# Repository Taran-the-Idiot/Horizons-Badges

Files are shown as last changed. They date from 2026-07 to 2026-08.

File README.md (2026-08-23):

# Horizons Crux Badges



E-ink badges for Horizons Crux! Made in Kicad. They use 2.66" E-ink screens with an RP2040 mcu. And they are made in the shape of a mantaray :D

Just use a piece of double sided tape to secure down the screen and you are good to go!

Features: 

- usbC connector
- 2.66" E-ink
- No battery required
- Has a lanyard hole

## Schematic



Here is the schematic for this board. It is a normal rp2040 microcontroller with an E-ink driver integrated into it. 

## PCB



Here is the pcb layout and design. This is a 2 layer board that has a ground pour, as well as a 3v3 pour on the top side over where the mcu electronics are. 

The files for the individual art sections can be found labelled in the [/art](/art) directory.

### Art

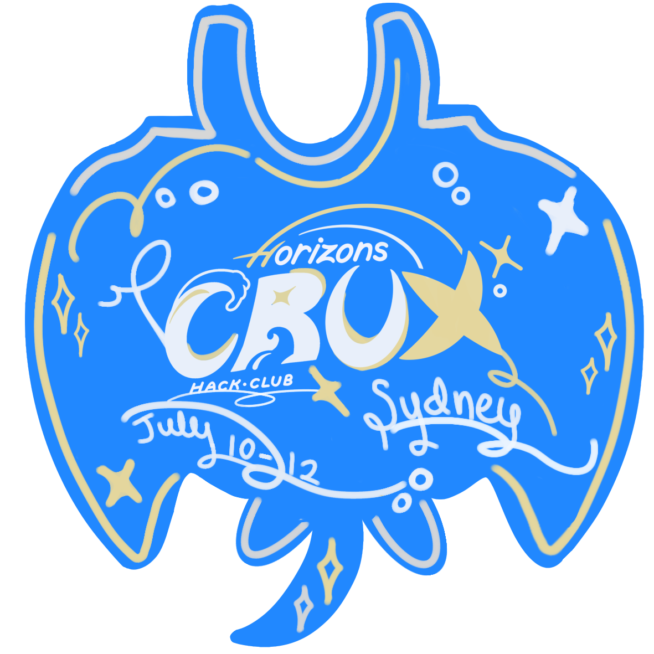
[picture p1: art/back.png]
fkdsjflkd


The art was drawn by [@variidian](https://github.com/variidian). The original art files and the vectorised sections for pcb production can be found in the [/art](/art) folder. 

## Firmware

The badge can be flashed using the [Badge Paint Website](https://badge-paint.notaroomba.dev/).

You draw what you want or load in the preset and fill in the details. you then need to flash a micropython .uf2 and it will then allow you to flash the badge.

This site was made by [@notaroomba](https://github.com/notaroomba)

#### Credits

Credit to [@variidian](https://github.com/variidian) for making the art for the badge and credit to [@notaroomba](https://github.com/notaroomba) for writing the software.

Also a thank you to [JLCPCB](https://jlcpcb.com) for sponsoring the badges!

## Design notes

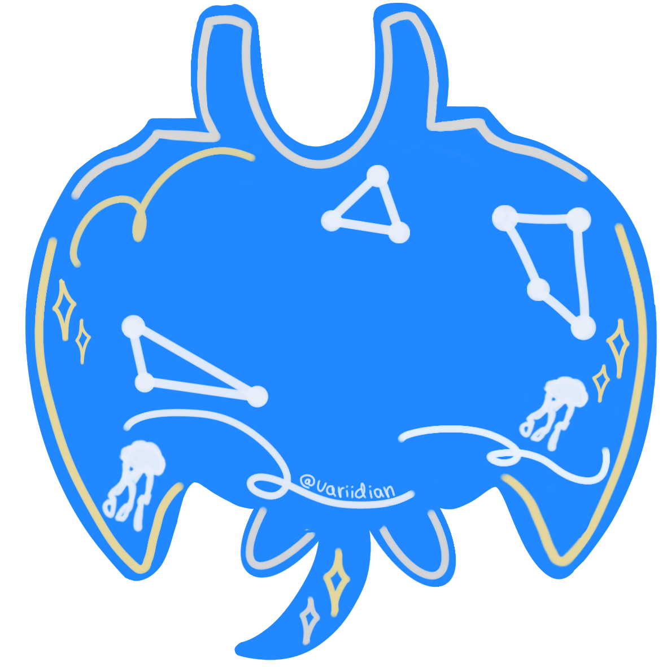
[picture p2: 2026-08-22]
art/front.png

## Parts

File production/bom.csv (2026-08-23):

Designator | Footprint | Quantity | Value | LCSC Part #
C1, C20, C22, C23, C24, C25, C26, C27, C28, C29, C9 | 0402 | 11 | 1uf
C10, C11, C12, C17, C2, C21, C3, C4, C5, C6, C7, C8 | 0402 | 12 | 100nf
C13, C14 | 0603 | 2 | 33pf
C15, C16 | 0603 | 2 | 10uf
C18, C19 | 0402 | 2 | 4.7uf
D1 | 0805 | 1 | C2293
D2, D3, D4 | SOD-123_L2.8-W1.8-LS3.7-RD | 3 | MBR0530
J1 | USB-C-SMD_20P-P0.50-L6.5-W8.9 | 1 | C309365
L1 | IND-SMD_L4.0-W4.0_FNR40XXS | 1 | 10uh 1A
Q1 | SOT-23 | 1 | C5122027
R1, R4, R5 | 0402 | 3 | 1k
R10 | 0402 | 1 | 0.47
R11 | 0603 | 1 | 10k
R2 | 0402 | 1 | 10k
R3 | 0402 | 1 | 2.2k
R6, R7 | 0402 | 2 | 22
R8, R9 | 0402 | 2 | 5.1k
SW1, SW2 | C720477 | 2 | C720477
U1 | QFN-56-1EP_7x7mm_P0.4mm_EP3.2x3.2mm_ThermalVias | 1 | C2040
U2 | SOIC-8_5.3x5.3mm_P1.27mm | 1 | W25Q16JVSS
U3 | FPC-SMD_24P-P0.50_05A20L24P | 1 | ~
U4 | SOT-23 | 1 | XC6206P332MR
U5 | SOT-23-6 | 1 | USBLC6-2SC6
Y1 | CRYSTAL-SMD_4P-L3.2-W2.5-BL | 1 | C9002

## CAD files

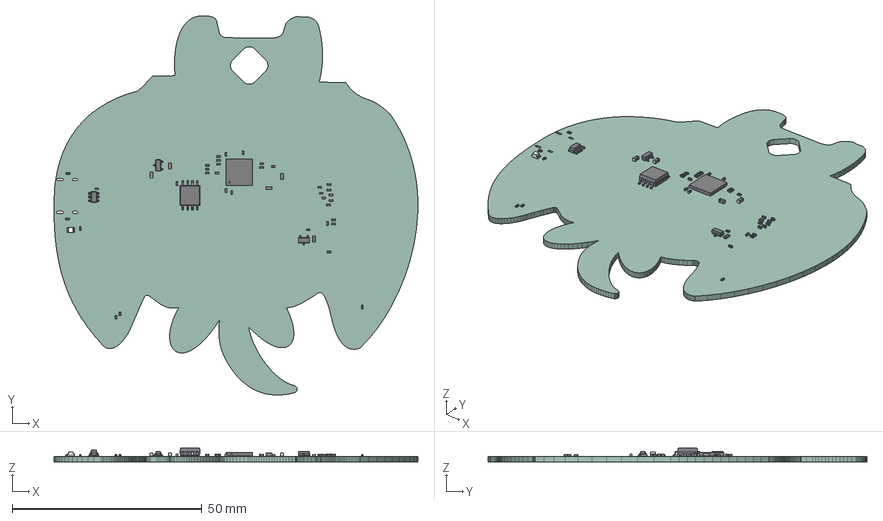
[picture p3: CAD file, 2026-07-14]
PCB/pcb.step
96.0 x 99.9 x 3.75 mm
LED_0805_2012Metric
C_0402_1005Metric x 25
R_0402_1005Metric x 10
C_0603_1608Metric x 4
SOT-23-6
SOT-23 x 2
R_0603_1608Metric
QFN-56-1EP_7x7mm_P0.4mm_EP3.2x3.2mm
SOIC-8_5.3x5.3mm_P1.27mm
PCB_PCB

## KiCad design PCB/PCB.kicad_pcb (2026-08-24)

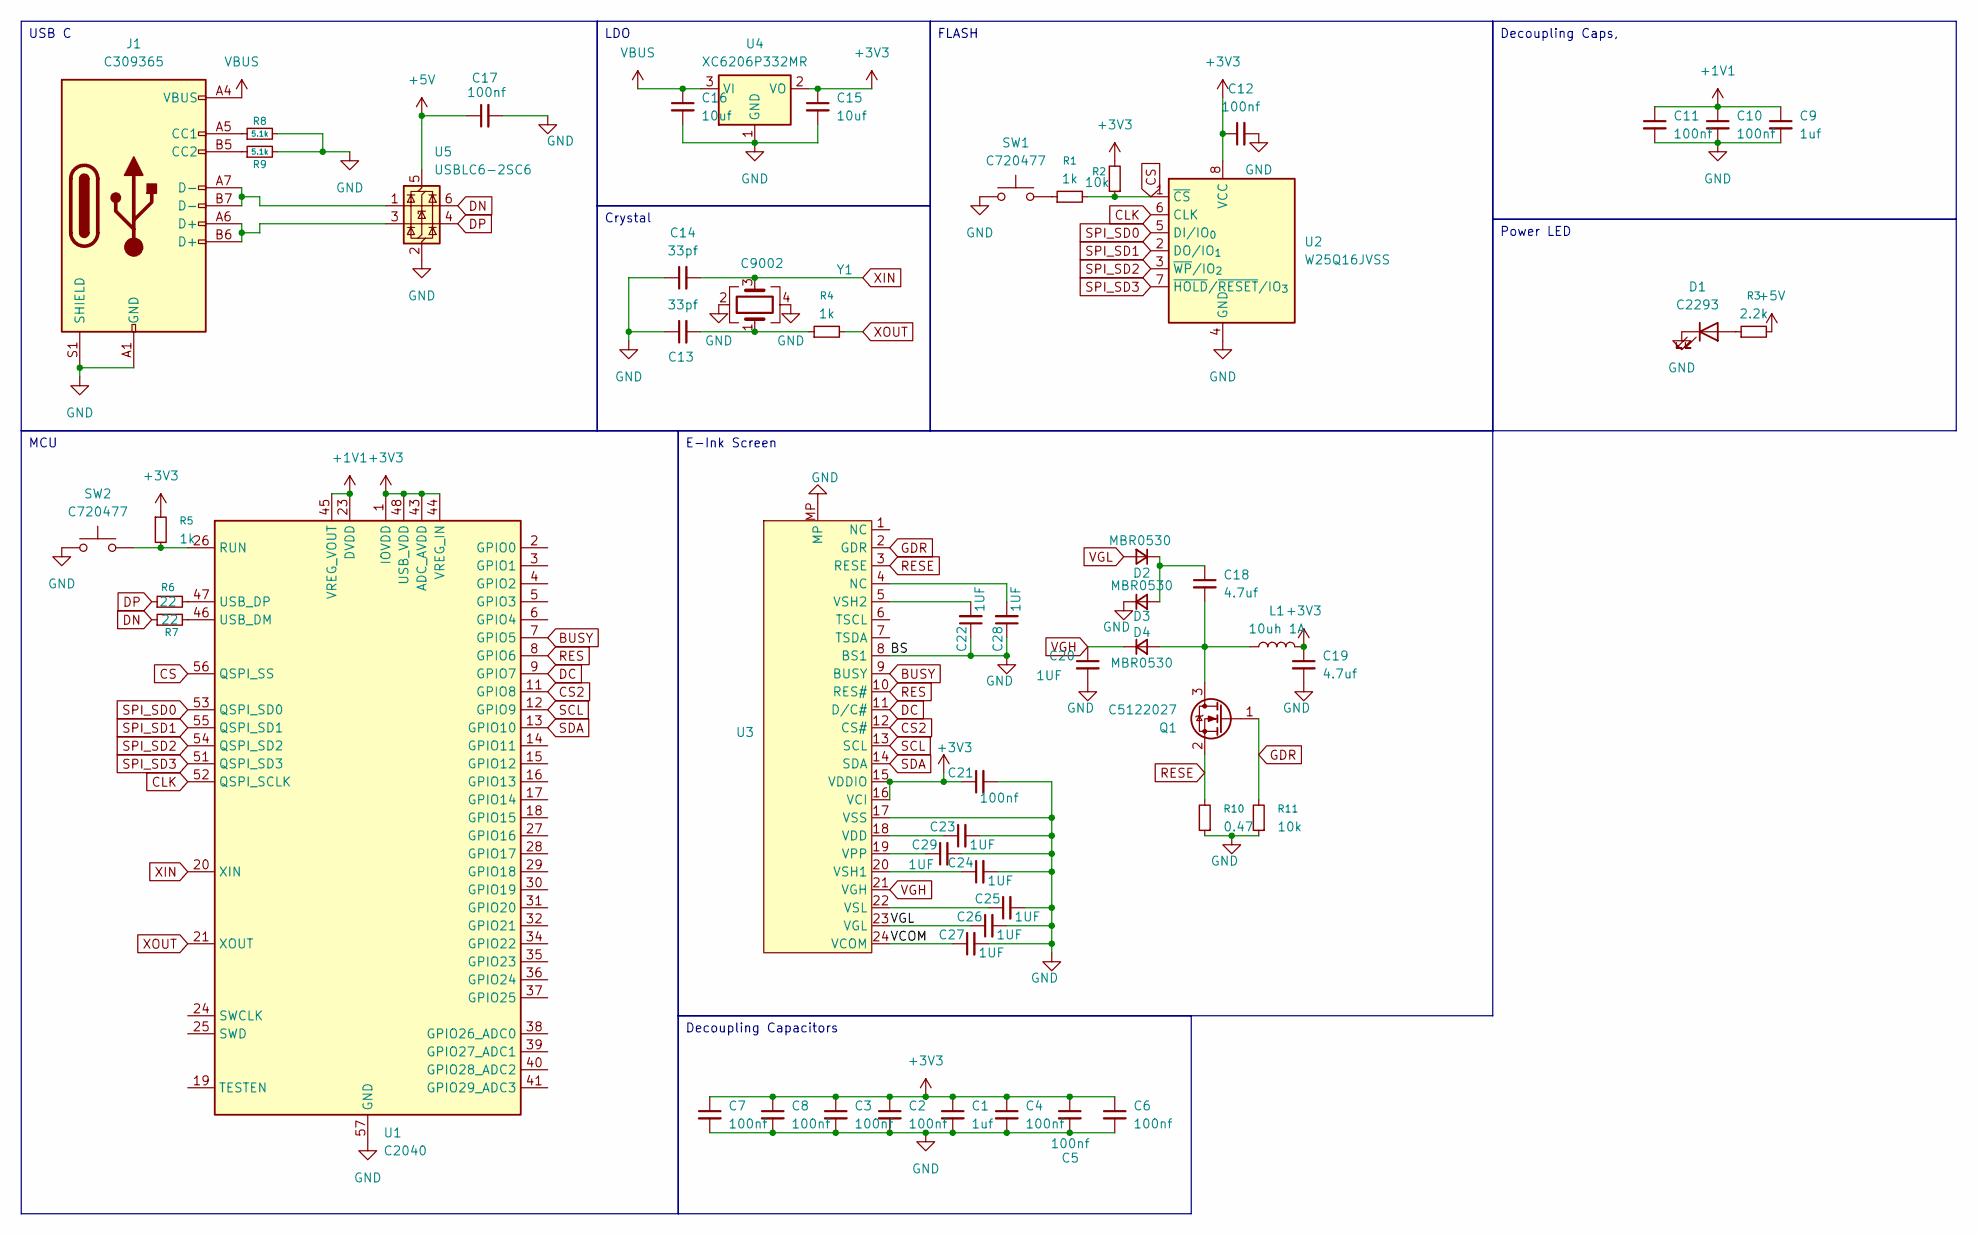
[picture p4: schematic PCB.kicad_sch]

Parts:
C1, C9: 1uf; C_0402_1005Metric
C2, C3, C4, C5, C6, C7, C8, C10, C11, C12, C17, C21: 100nf; C_0402_1005Metric
C13, C14: 33pf; C_0603_1608Metric
C15, C16: 10uf; C_0603_1608Metric
C18, C19: 4.7uf; C_0402_1005Metric
C20, C22, C23, C24, C25, C26, C27, C28, C29: 1UF; C_0402_1005Metric
D1: C2293; LED_0805_2012Metric
D2, D3, D4: MBR0530; SOD-123_L2.8-W1.8-LS3.7-RD
J1: C309365; USB-C-SMD_20P-P0.50-L6.5-W8.9
L1: 10uh 1A; IND-SMD_L4.0-W4.0_FNR40XXS
Q1: C5122027; SOT-23
R1, R4, R5: 1k; R_0402_1005Metric
R2: 10k; R_0402_1005Metric
R3: 2.2k; R_0402_1005Metric
R6, R7: 22; R_0402_1005Metric
R8, R9: 5.1k; R_0402_1005Metric
R10: 0.47; R_0402_1005Metric
R11: 10k; R_0603_1608Metric
SW1, SW2: C720477
U1: C2040; QFN-56-1EP_7x7mm_P0.4mm_EP3.2x3.2mm_ThermalVias
U2: W25Q16JVSS; SOIC-8_5.3x5.3mm_P1.27mm
U3: FPC-SMD_24P-P0.50_05A20L24P
U4: XC6206P332MR; SOT-23
U5: USBLC6-2SC6; SOT-23-6
Y1: C9002; CRYSTAL-SMD_4P-L3.2-W2.5-BL

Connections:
+1V1: C9.1, C10.1, C11.1, U1.23 (DVDD), U1.45 (VREG_VOUT), U1.50 (DVDD)
+3V3: C1.1, C2.1, C3.1, C4.1, C5.1, C6.1, C7.1, C8.1, C12.1, C15.1, C19.1, C21.1, L1.2, R2.2, R5.1, U1.1 (IOVDD), U1.10 (IOVDD), U1.22 (IOVDD), U1.33 (IOVDD), U1.42 (IOVDD), U1.43 (ADC_AVDD), U1.44 (VREG_IN), U1.48 (USB_VDD), U1.49 (IOVDD), U2.8 (VCC), U3.15 (VDDIO), U3.16 (VCI), U4.2 (VO)
+5V: C17.1, R3.2, U5.5 (VBUS)
/VCOM: C27.1, U3.24 (VCOM)
BUSY: U1.7 (GPIO5), U3.9 (BUSY)
CLK: U1.52 (QSPI_SCLK), U2.6 (CLK)
CS: R1.2, R2.1, U1.56 (QSPI_SS), U2.1 (~CS)
CS2: U1.11 (GPIO8), U3.12 (CS#)
DC: U1.9 (GPIO7), U3.11 (D/C#)
DN: R7.1, U5.6 (I/O1)
DP: R6.1, U5.4 (I/O2)
GDR: Q1.1 (G), R11.2, U3.2 (GDR)
GND: C1.2, C2.2, C3.2, C4.2, C5.2, C6.2, C7.2, C8.2, C9.2, C10.2, C11.2, C12.2, C13.1, C14.1, C15.2, C16.2, C17.2, C19.2, C20.2, C21.2, C22.1, C23.2, C24.2, C25.2, C26.2, C27.2, C28.1, C29.2, D1.1 (K), D3.1 (K), J1.A1 (GND), J1.A12 (GND), J1.B1 (GND), J1.B12 (GND), J1.S1 (SHIELD), R8.2, R9.2, R10.1, R11.1, SW1.1, SW2.1, U1.57 (GND), U2.4 (GND), U3.8 (BS1), U3.17 (VSS), U3.MP, U4.1 (GND), U5.2 (GND), Y1.2, Y1.4
unnamed: C13.2, R4.1, Y1.1
unnamed: C28.2, U3.4 (NC)
unnamed: D1.2 (A), R3.1
unnamed: C18.1, D2.1 (K), D3.2 (A)
unnamed: C18.2, D4.2 (A), L1.1, Q1.3 (D)
unnamed: J1.A5 (CC1), R8.1
unnamed: J1.B5 (CC2), R9.1
unnamed: J1.A6 (D+), J1.B6 (D+), U5.3 (I/O2)
unnamed: J1.A7 (D-), J1.B7 (D-), U5.1 (I/O1)
unnamed: R1.1, SW1.2
unnamed: R5.2, SW2.2, U1.26 (RUN)
unnamed: R7.2, U1.46 (USB_DM)
unnamed: R6.2, U1.47 (USB_DP)
unnamed: C23.1, U3.18 (VDD)
unnamed: C29.1, U3.19 (VPP)
unnamed: C24.1, U3.20 (VSH1)
unnamed: C22.2, U3.5 (VSH2)
unnamed: C25.1, U3.22 (VSL)
RES: U1.8 (GPIO6), U3.10 (RES#)
RESE: Q1.2 (S), R10.2, U3.3 (RESE)
SCL: U1.12 (GPIO9), U3.13 (SCL)
SDA: U1.13 (GPIO10), U3.14 (SDA)
SPI_SD0: U1.53 (QSPI_SD0), U2.5 (DI/IO_{0})
SPI_SD1: U1.55 (QSPI_SD1), U2.2 (DO/IO_{1})
SPI_SD2: U1.54 (QSPI_SD2), U2.3 (~WP/IO_{2})
SPI_SD3: U1.51 (QSPI_SD3), U2.7 (~HOLD/~RESET/IO_{3})
VBUS: C16.1, J1.A4 (VBUS), J1.A9 (VBUS), J1.B4 (VBUS), J1.B9 (VBUS), U4.3 (VI)
VGH: C20.1, D4.1 (K), U3.21 (VGH)
VGL: C26.1, D2.2 (A), U3.23 (VGL)
XIN: C14.2, U1.20 (XIN), Y1.3
XOUT: R4.2, U1.21 (XOUT)

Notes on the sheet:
USB C
Crystal
Decoupling Capacitors
FLASH
MCU
E-Ink Screen
LDO
Decoupling Caps,
Power LED

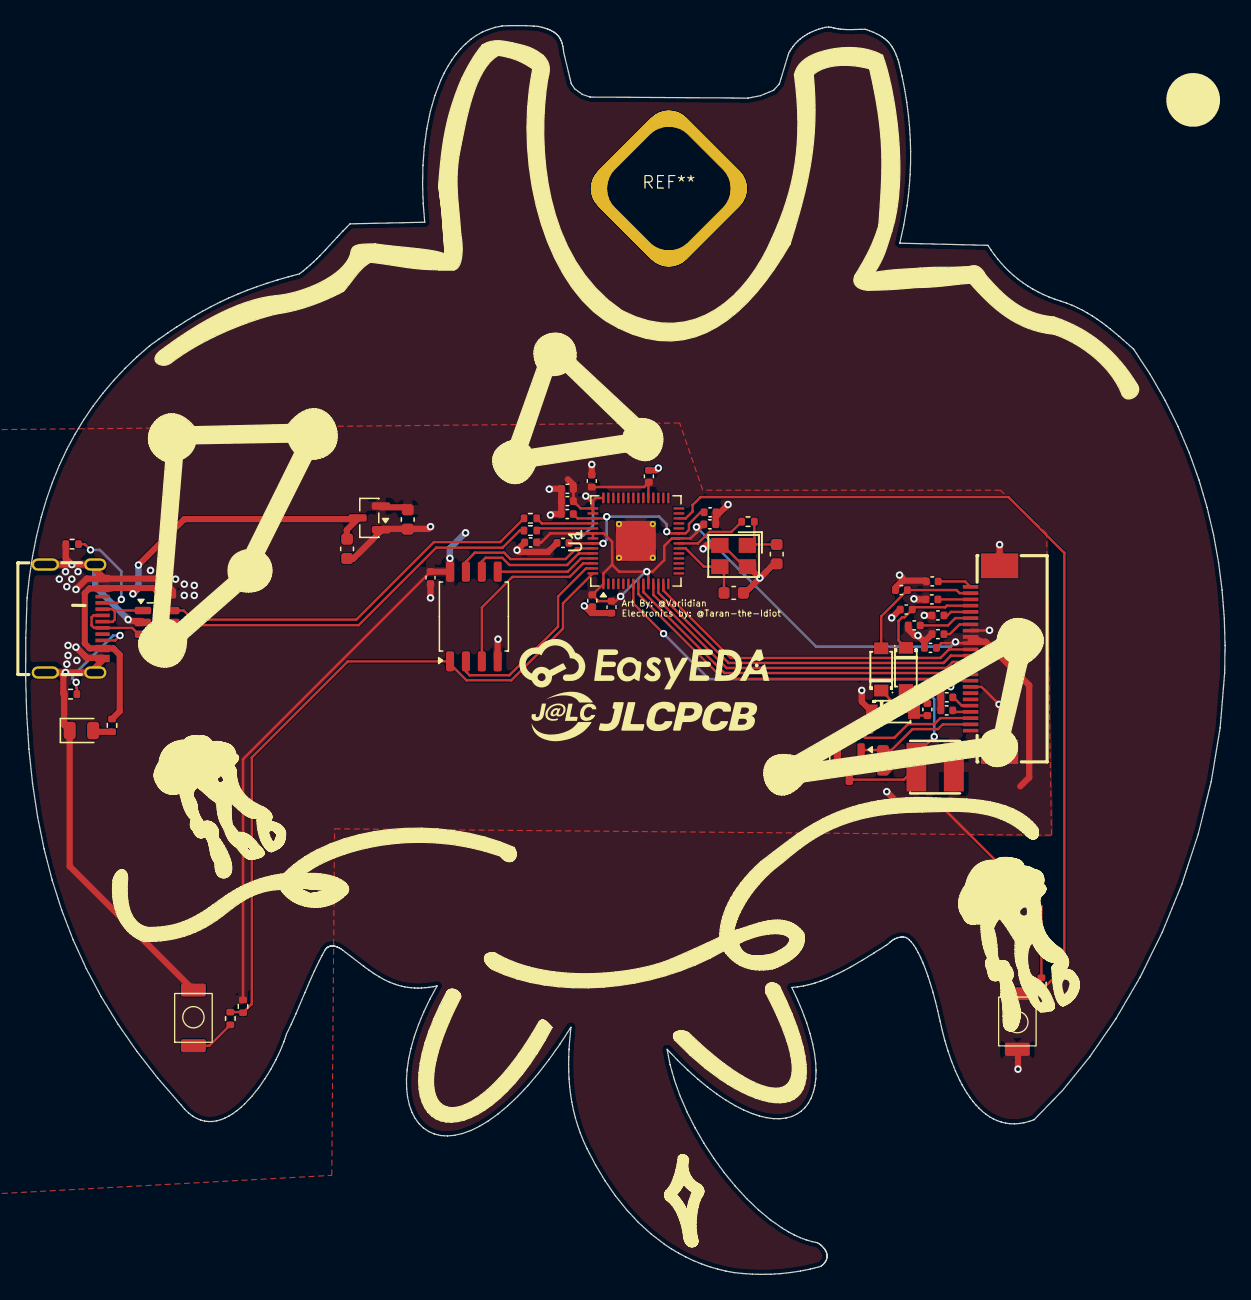
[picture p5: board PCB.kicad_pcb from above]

Board: 2 copper layers, 96.0 x 99.9 mm, 55 parts (0 on the bottom side), 44 nets.

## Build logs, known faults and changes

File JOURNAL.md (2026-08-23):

# Horizons crux badges

total time spent: 23.5 hours

## 29th of May

Started work on the badges



Basic rp2040 starting stuff. the text boxes are there because people say wah wah wah organise your schematics. so here I am organising my schematic for the first time ever.



usbc with the esd protection thingy and the ldo. made it the same as I did for the dev board



I did however change these resistor values after a discussion with kai and nimit where I found out that the value actually matters. 20k means that this device is the dominant one over the device its connected to, 5.1k means its the submission device that listens to what the other device tells it to do like a good boy(girl?, thing?, idk).



got this reference diagram out from the datasheet of the e ink that I plan to use



Made the first bit and flipped it because my e ink footprint is flipped and otherwise it would be a bit trippy



Did the e ink fpc side of things.

bleh

Added the tags to the microcontroller



In the end this is what that circuit looks like

Time spent: 1 hour

## 30th of May



Found a inductor that works with the specs needed and is a good size



got the art for it from shurui. this was just the preview but it works enough for me to get a start until she wakes up from eep and gets me the full file



First I dumped all the parts and kinda positioned them roughly where I wanted



I turned the screenshot of the preview into a reverse silkscreen footprint so I could have an outline on where to put stuff



im placing the usb at an angle on the bottom left so it can avoid the e ink and also avoid an overglade situation where the e ink was pressed against the usbc port and broke



So the traces are like very scuffed because I have it at a 35 degree angle. ts is stupidly difficult to trace and manage too



Screw it im just gonna move it here

its pretty close to the e ink but thats a problem for later me

(the silkscreen rectangle is an outline of the eink screen btw. I use it to get a scale of reference for stuff)



okay so when i made that last one, i used kicads image to footprint converter to give it a set height of 100mm but i forgot to account for the fact that there was a bunch of padding on either side so the actual workable area became smaller. so I cropped my ss to be nearly touching



gave everything general positions



I now have a ton more clearance and a ton more space between the usbc and the E ink



changed the resistance on the idicator led from 2.2 ohms to 2.2k ohms. I am no longer putting 2 amps of current through a led



Positioned the parts for the e ink part and got them ready to route





positioned the decoupling caps and resistors for the 2040



And there are the rest of the caps and the crystal



I moved the whole 2040 up and under the screen becaude there is easier pin access to it that way and there is also easier positioning for the flash since needs to be under the 2040 or else it needs to cross the data lines



Routed the ldo, flash and decoupling caps



And also did the usbc



routed the data lines to the microcontroller. I had to use 2 vias and rmove the decoupling cap because they wouldnt all fit



Routed the rest of the e ink thingy. kinda feels messy but eh.



so the rese and res pins are actually different and I had them put down as the same on the schematic so I fixed that



I put the cap here



and routed with vias



I was also told that I did not need 3v3 traces that thick so i went and made thm all thin.



added a pour and thats the routing done

Time spent: 3 hours

## 31st of May



I now have access to the art and shall begin tracing and porting everything over to kicad. since its a png and all on one layer, I need to separate it and turn it into an svg

This is like a really stupidly long process that includes putting down a bunch of spline points and adjusting the spline to fit all the curves and stuff



I did the cutlines, imported it into kicad and now it looks like this



I did the top mask layer



Importing it in, it looks like this now. it was a bit difficult to line it up properly though



starting top silkscreen and did one of the jellyfish. this is how many points there are. its actually such a pain. trick to doing this though is to just put a point at all the corners and points where the curve changes. and then use the line curve tool to make it match the curve its on. you could make a million points but imo this is quicker



did the top thing 

gonna just image dump since its all pretty repetitive anyways







Done that layer. on to the next

I also added that dot at the top as a reference dot. since kicad imports all the layers and uses different centre points for each layer, I added the dot so i could export it with every layer and use it to line everything up.



Starting on the other layer, some of the stuff already matches so saves a bit of time for me, other stuff I need to still do/edit though



yeah this side is going to be like 10x harder than the last one

I just put down all the points first and will now be smoothing this whole thing out

Time spent: 3.5 hours

## 1st-2nd of June



I spent these 2 days doing this and didnt really take any other ss because its all the same repetitive thing anyways



mask layer ^^



Silkscreen layer ^^^^^^

Time spent over those 2 days: 7 hours

## 3rd of June



Imported the layers into kicad and noticed some errors so i fixed them up manually. it was only like a 0.05mm gap but eh. helps sooth my ocd



this is the final badge design!

(low quality image because this is the plugged into jlc version that shows the mask properly since kicad doesnt delete any silkscreen with bare copper underneath it.)

after that just finished the bom and got the jlc price

Time spent: 1.5 hours

## 5th of June

I went and got a design review from cyao, he gave me a whole essay of stuff to fix



changed these to 90. my references were wrong



Fixed this up because I missed some stuff plus had some wrong numbers or the datasheet was wrong or smth idk



changed the model of this to a cheaper one



Swapped to a footprint with thermal relief vias



was told to add more vias for ground near the port and also added an amogus

made some other smaller changes

Time Spent: 2 hours

## 6th of june

Made some more changes from the cyao feedback





added a power plane for 3v3. was have made it the entire top layer but i have a lot of exposed copper so it might be dangerous or easily short and it really isnt needed in the places where there isnt any electronics so I just put it there so its better

I had to fiddle a lot with all the traces and stuff and how to actually implement the pour. I did some research and ended up with this. There was also a lot of re-routing and stuff, I had to move around a bunch of the parts for the e ink thing to fit in the extra 3 capacitors and I also needed to move stuff around because of the pour change and ground all needing to be routed differently. 



I went and changed up the names for everything on my schematic to include lcsc part numbers and also to change the 0.1uf caps into 100nf caps since they always error out jlc

Need to get another review now



I changed the power pour a bit to get rid of the risk of a shot on the solder mask cutout there and then rerouted stuff accordingly

Time spent: 4.5 hours

# July 8th

Spent 1 hour on firmware. I was using both [this code by nimit](https://github.com/nimitvijayvargee/overgladebadgefw) and the [waveshare micropython driver](https://github.com/waveshareteam/Pico_ePaper_Code) but could not get it to work well.

Time Spent: 1 hour

# July 9th

Spent 2 more hours on firmware.



I kept running into this issue where not all the pixels would be responsive. I spent a while trying to debug this to no avail. I eventually just gave up and on the event day, nathan(notaroomba) went and clauded up a solution [https://badge-paint.notaroomba.dev/](https://badge-paint.notaroomba.dev/)

Time Spent: 2 hours

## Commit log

2026-06-05 commit beeg stuff(i forgor to commit for a while)
    [PCB.kicad_pcb]
2026-06-06 journal 1
    [PCB.kicad_pcb, PCB.kicad_sch]
2026-06-09 Cleanup Schematic
    [PCB.kicad_sch]
2026-06-11 anything except engineering
    [PCB.kicad_pcb]
